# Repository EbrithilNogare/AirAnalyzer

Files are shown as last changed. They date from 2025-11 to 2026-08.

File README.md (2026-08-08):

# 🌡️ AirAnalyzer

A DIY ESP32-based environmental monitor with an e-paper display!

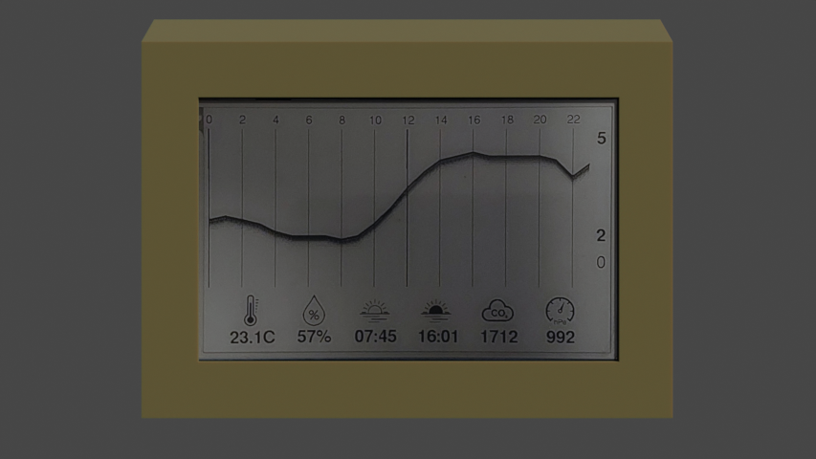
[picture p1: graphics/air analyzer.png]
Device
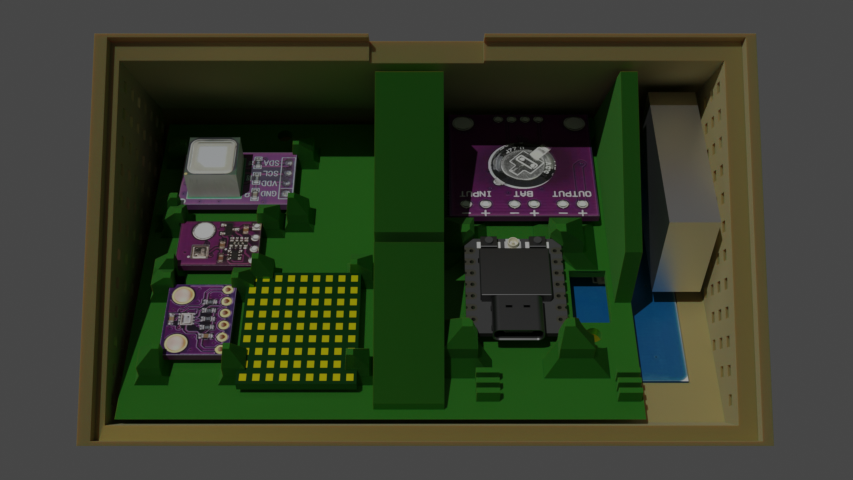
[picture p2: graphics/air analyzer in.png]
Internals
|||
|:--:|:--:|
|Outside|Inside|

## What it does

- Measures **temperature**, **humidity**, **CO2**, and **pressure**
- Fetches **weather forecast** from Open-Meteo API
- Shows **sunrise/sunset** times
- Uploads data to **ThingSpeak**
- Runs on **deep sleep** for low power consumption

## Hardware

- ESP32-C3
- SCD40 (CO2 sensor)
- SHT4x (temperature & humidity)
- BMP280 (pressure)
- 3.97" e-paper display

## Connections

```mermaid
---
config:
  layout: elk
---
flowchart LR
    ESP["ESP32-C3<br>Seeed Studio"] -- "3V3 - VCC<br>GND - GND<br>GPIO 6 - SDA<br>GPIO 7 - SCL<br>BAT+ - BAT+<br>BAT- - BAT-" --- Board["Board"]

    Board -- "VCC - VCC<br>GND - GND<br>SCL - SCL<br>SDA - SDA" --- SCD40["SCD40"] & SHT4x["SHT4x"] & BMP280["BMP280"]

    ESP -- "GPIO 20 - Base" --- Transistor["BC327 PNP Transistor"]
    Transistor -- "Collector - VCC" --- Display["E-Paper Display"]
    ESP -- "GPIO 9 - PWR" --- Display
    ESP -- "GPIO 3 - BUSY" --- Display
    ESP -- "GPIO 4 - RST" --- Display
    ESP -- "GPIO 5 - DC" --- Display
    ESP -- "GPIO 21 - CS" --- Display
    ESP -- "GPIO 8 - SCLK" --- Display
    ESP -- "GPIO 10 - DIN" --- Display
    ESP -- "GND - GND" --- Display
    ESP -- "3V3 - Emitter" --- Transistor

    ESP -- "BAT+ - BAT+" --- Charger["CJMCU-2557"]
    ESP -- "BAT- - BAT-" --- Charger
    Battery["LiPo Battery<br>500 mAh"] -- "Positive - BAT+" --- Charger
    Battery -- "Negative - BAT-" --- Charger
    Solar["Solar Panel"] -- "Positive - Input +" --- Charger
    Solar -- "Negative - Input -" --- Charger
    Solar -- "Zener diode (1N4733 5V1)" --- Solar

    ESP:::controller
    Board:::board
    SCD40:::sensor
    SHT4x:::sensor
    BMP280:::sensor
    Transistor:::transistor
    Display:::display
    Charger:::charger
    Battery:::battery
    Solar:::solar

    classDef controller stroke:#818cf8,fill:#eef2ff
    classDef board stroke:#fb923c,fill:#fff7ed
    classDef sensor stroke:#4ade80,fill:#f0fdf4
    classDef transistor stroke:#f87171,fill:#fef2f2
    classDef display stroke:#a78bfa,fill:#f5f3ff
    classDef charger stroke:#22d3ee,fill:#ecfeff
    classDef battery stroke:#facc15,fill:#fefce8
    classDef solar stroke:#fb923c,fill:#fff7ed
```

## Setup

1. Copy `include/config.example.h` to `include/config.h`
2. Add your WiFi credentials and ThingSpeak API key
3. Build & upload with PlatformIO

---

_Icons converted using [image2cpp](https://javl.github.io/image2cpp/)_

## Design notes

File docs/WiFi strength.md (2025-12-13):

# Consumtion estimation

| Power | Consumtion |
| ---: | ---: |
| -1 dBm | 165 mA |
| 2 dBm | 170 mA |
| 5 dBm | 178 mA |
| 7 dBm | 185 mA |
|  8.5 dBm | 192 mA |
| 11 dBm | 205 mA |
| 13 dBm | 220 mA |
| 15 dBm | 240 mA |
| 17 dBm | 260 mA |
| 18.5 dBm | 277 mA |
| 19 dBm | 285 mA |
| 19.5 dBm | 300 mA |

# Wifi connection measurement

## WIFI_PS_NONE

| Power Level | Success | Failed | Success% | Min(ms) | Avg(ms) | Max(ms) |
| ---: | ---: | -----: | ---: | ---: | ---: | ---: |
| -1dBm | 10 | 0 | 100.0% | 917 | 1321 | 1516 |
| 2dBm | 10 | 0 | 100.0% | 917 | 1330 | 1624 |
| 5dBm | 10 | 0 | 100.0% | 914 | 1260 | 1664 |
| 7dBm | 10 | 0 | 100.0% | 960 | 1298 | 1679 |
| 8.5dBm | 10 | 0 | 100.0% | 914 | 1160 | 1490 |
| 11dBm | 10 | 0 | 100.0% | 915 | 1334 | 1501 |
| 13dBm | 10 | 0 | 100.0% | 979 | 1380 | 1558 |
| 15dBm | 10 | 0 | 100.0% | 926 | 1299 | 1594 |
| 17dBm | 10 | 0 | 100.0% | 914 | 1294 | 1613 |
| 18.5dBm | 10 | 0 | 100.0% | 966 | 1324 | 1518 |
| 19dBm | 10 | 0 | 100.0% | 912 | 1100 | 1486 |
| 19.5dBm | 10 | 0 | 100.0% | 920 | 1151 | 1545 |

## WIFI_PS_MAX_MODEM

| Power Level | Success | Failed | Success% | Min(ms) | Avg(ms) | Max(ms) |
| ---: | ---: | -----: | ---: | ---: | ---: | ---: |
| -1dBm | 10 | 0 | 100.0% | 939 | 1485 | 2173 |
| 2dBm | 10 | 0 | 100.0% | 972 | 1304 | 1695 |
| 5dBm | 10 | 0 | 100.0% | 1003 | 1276 | 1608 |
| 7dBm | 10 | 0 | 100.0% | 915 | 1421 | 1647 |
| 8.5dBm | 10 | 0 | 100.0% | 915 | 1365 | 1836 |
| 11dBm | 10 | 0 | 100.0% | 976 | 1313 | 1782 |
| 13dBm | 10 | 0 | 100.0% | 959 | 1335 | 1575 |
| 15dBm | 10 | 0 | 100.0% | 916 | 1411 | 1578 |
| 17dBm | 10 | 0 | 100.0% | 911 | 1476 | 1931 |
| 18.5dBm | 10 | 0 | 100.0% | 914 | 1400 | 1615 |
| 19dBm | 10 | 0 | 100.0% | 998 | 1356 | 1591 |
| 19.5dBm | 10 | 0 | 100.0% | 984 | 1411 | 1671 |

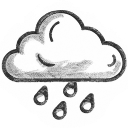
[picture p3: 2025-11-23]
graphics/rain.png

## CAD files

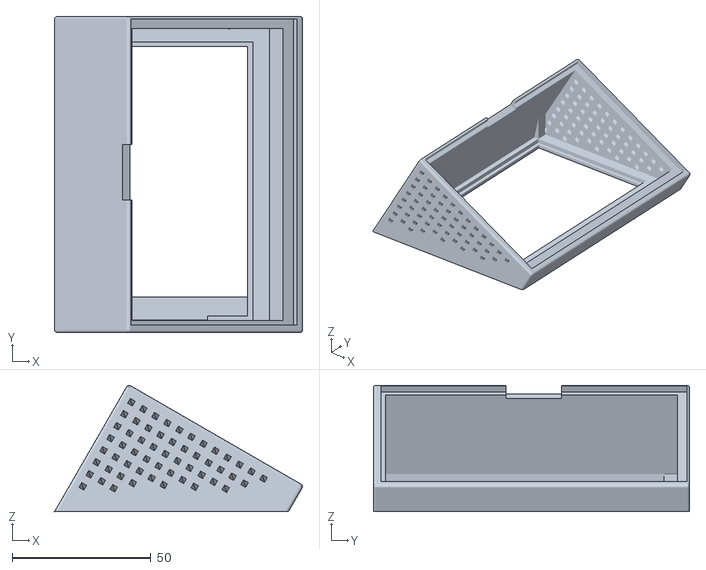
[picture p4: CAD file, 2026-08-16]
models/bottom part.stl
89.4 x 114.0 x 45.5

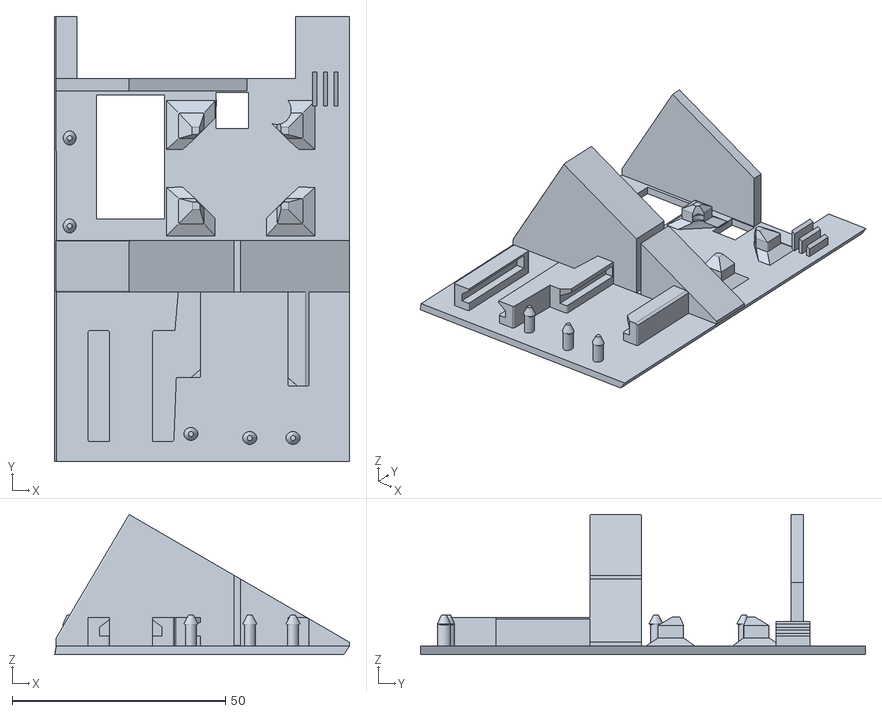
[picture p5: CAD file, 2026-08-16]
models/middle part.stl
69.1 x 104.3 x 32.8

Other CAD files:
models/air analyzer.blend

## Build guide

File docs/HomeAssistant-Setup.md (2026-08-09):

# Home Assistant Setup Guide

This guide explains how to set up Home Assistant to receive sensor data from your AirAnalyzer device.

## Overview

The AirAnalyzer sends the following sensor data to Home Assistant:

- **temperature**: Air temperature from SHT4x sensor (°C)
- **temperature_esp**: ESP32 internal temperature (°C)
- **humidity**: Relative humidity from SHT4x sensor (%)
- **co2**: CO₂ concentration from SCD40 sensor (ppm)
- **pressure**: Atmospheric pressure from BMP280 sensor (hPa)
- **battery_voltage**: Battery voltage (V)
- **temperature_scd**: Air temperature from SCD40 sensor (°C)
- **humidity_scd**: Relative humidity from SCD40 sensor (%)
- **wifi_rssi**: WiFi signal strength (dBm)

## Setup Steps

### 1. Create Webhook Automation in Home Assistant

1. Go to **Settings** → **Automations & Scenes**
2. Click **+ Create Automation** → **Create new automation**
3. Click the **⋮** menu → **Edit in YAML**
4. Replace with this configuration:

```yaml
alias: AirAnalyzer Data Receiver
description: Receives sensor data from AirAnalyzer device
trigger:
  - platform: webhook
    webhook_id: air_analyzer # use real id, as it is as password
    allowed_methods:
      - POST
    local_only: true
condition: []
action:
  - event: air_analyzer_data_received
    event_data:
      temperature: "{{ trigger.json.temperature }}"
      temperature_esp: "{{ trigger.json.temperature_esp }}"
      humidity: "{{ trigger.json.humidity }}"
      co2: "{{ trigger.json.co2 }}"
      pressure: "{{ trigger.json.pressure }}"
      battery_voltage: "{{ trigger.json.battery_voltage }}"
      temperature_scd: "{{ trigger.json.temperature_scd }}"
      humidity_scd: "{{ trigger.json.humidity_scd }}"
      wifi_rssi: "{{ trigger.json.wifi_rssi }}"
mode: single
```

5. Click **Save**

### 2. Add Sensors to Configuration

Add the following to your `configuration.yaml`:

```yaml
# AirAnalyzer Sensors
template:
  - trigger:
      - platform: event
        event_type: air_analyzer_data_received
    sensor:
      - name: "Air Analyzer Temperature"
        unique_id: air_analyzer_temperature
        state: "{{ trigger.event.data.temperature }}"
        unit_of_measurement: "°C"
        device_class: temperature
        state_class: measurement
      - name: "Air Analyzer Humidity"
        unique_id: air_analyzer_humidity
        state: "{{ trigger.event.data.humidity }}"
        unit_of_measurement: "%"
        device_class: humidity
        state_class: measurement
      - name: "Air Analyzer CO₂"
        unique_id: air_analyzer_co2
        state: "{{ trigger.event.data.co2 }}"
        unit_of_measurement: "ppm"
        device_class: carbon_dioxide
        state_class: measurement
      - name: "Air Analyzer Pressure"
        unique_id: air_analyzer_pressure
        state: "{{ trigger.event.data.pressure }}"
        unit_of_measurement: "hPa"
        device_class: atmospheric_pressure
        state_class: measurement
      - name: "Air Analyzer Battery"
        unique_id: air_analyzer_battery
        state: "{{ trigger.event.data.battery_voltage }}"
        unit_of_measurement: "V"
        device_class: voltage
        state_class: measurement
      - name: "Air Analyzer ESP Temperature"
        unique_id: air_analyzer_esp_temperature
        state: "{{ trigger.event.data.temperature_esp }}"
        unit_of_measurement: "°C"
        device_class: temperature
        state_class: measurement
      - name: "Air Analyzer SCD Temperature"
        unique_id: air_analyzer_scd_temperature
        state: "{{ trigger.event.data.temperature_scd }}"
        unit_of_measurement: "°C"
        device_class: temperature
        state_class: measurement
      - name: "Air Analyzer SCD Humidity"
        unique_id: air_analyzer_scd_humidity
        state: "{{ trigger.event.data.humidity_scd }}"
        unit_of_measurement: "%"
        device_class: humidity
        state_class: measurement
      - name: "Air Analyzer WiFi RSSI"
        unique_id: air_analyzer_wifi_rssi
        state: "{{ trigger.event.data.wifi_rssi }}"
        unit_of_measurement: "dBm"
        device_class: signal_strength
        state_class: measurement
      - name: "Air Analyzer Last Seen"
        unique_id: air_analyzer_last_seen
        device_class: timestamp
        state: "{{ now() }}"
```

After adding this, restart Home Assistant.

### 3. Add Sensors to Dashboard

The sensors will appear as:

- `sensor.air_analyzer_temperature`
- `sensor.air_analyzer_humidity`
- `sensor.air_analyzer_co2`
- `sensor.air_analyzer_pressure`
- `sensor.air_analyzer_battery`
- `sensor.air_analyzer_esp_temperature`
- `sensor.air_analyzer_scd_temperature`
- `sensor.air_analyzer_scd_humidity`
- `sensor.air_analyzer_wifi_rssi`

1. Go to your dashboard
2. Click **Edit Dashboard** → **+ Add Card** → **Entities Card**
3. Add these entities to display your sensor data

## Testing

### Test the Webhook

You can test the webhook from your computer using curl:

```bash
curl -X POST http://homeassistant.local:8123/api/webhook/XXXXX -H "Content-Type: application/json" -d '{ "temperature": 22.5, "temperature_esp": 35.2, "humidity": 45.3, "co2": 650, "pressure": 1013, "battery_voltage": 4.15, "temperature_scd": 22.8, "humidity_scd": 44.7, "wifi_rssi": -62 }'
```

If successful, you should see the values update in your Home Assistant helpers.

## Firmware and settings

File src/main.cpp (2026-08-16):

#include "PinConfig.h"
#include <Arduino.h>
#include <Wire.h>
#include <WiFi.h>
#include <HTTPClient.h>
#include <Adafruit_SHT4x.h>
#include <Adafruit_BMP280.h>
#include <SensirionI2CScd4x.h>
#include <GxEPD2_BW.h>
#include <ArduinoJson.h>
#include <esp_sleep.h>
#include <time.h>

#include "../include/config.h"
#include "rendering.h"
#include "home_assistant.h"



DisplayType display(GxEPD2_397_GDEM0397T81(EPD_CS_PIN, EPD_DC_PIN, EPD_RST_PIN, EPD_BUSY_PIN));
Adafruit_SHT4x sht4;
Adafruit_BMP280 bmp;
SensirionI2cScd4x scd4x;

float tempAir = NAN, humidity = NAN, tempESP = NAN, pressure = NAN, batteryVoltage = NAN, co2 = NAN, moonPhase = 0;
float tempSCD = NAN, humiditySCD = NAN;
int wifiRSSI = 0;


RTC_DATA_ATTR float rtc_forecastTemp[FORECAST_FETCH_HOURS];
RTC_DATA_ATTR float rtc_forecastApparentTemp[FORECAST_FETCH_HOURS];
RTC_DATA_ATTR float rtc_forecastRain[FORECAST_FETCH_HOURS];
RTC_DATA_ATTR char rtc_sunriseTimeStr[6] = "--:--";
RTC_DATA_ATTR char rtc_sunsetTimeStr[6] = "--:--";
RTC_DATA_ATTR int rtc_forecastStartHour = 0;
RTC_DATA_ATTR int rtc_forecastValidHours = 0;      // how many hours the last fetch actually returned
RTC_DATA_ATTR uint32_t rtc_forecastStartEpoch = 0; // epoch of forecast index 0, used to re-align the graph on the current hour
RTC_DATA_ATTR uint32_t rtc_lastWeatherSlot = 0;     // fetch slot whose data is already in RTC memory
RTC_DATA_ATTR bool rtc_weatherDataValid = false;
RTC_DATA_ATTR uint32_t rtc_bootCount = 0;
RTC_DATA_ATTR uint32_t rtc_ntpBaseEpoch = 0;            // Unix epoch at last NTP sync
RTC_DATA_ATTR uint64_t rtc_elapsedUs = 0;               // Microseconds elapsed since NTP sync
RTC_DATA_ATTR uint64_t rtc_priorAwakeUs = 0;            // Previous cycle awake time (XTAL-timed, accurate)
RTC_DATA_ATTR uint64_t rtc_priorSleepUs = 0;            // Previous cycle intended sleep duration

// Measured true-seconds-per-requested-second of the deep sleep timer (see calibrateSleepClock)
RTC_DATA_ATTR float rtc_clockScale = 1.0f;
RTC_DATA_ATTR uint64_t rtc_sleepUsSinceSync = 0;
RTC_DATA_ATTR uint64_t rtc_awakeUsSinceSync = 0;

RTC_DATA_ATTR int rtc_batteryPercent = 0;  // battery percentage shown on display
RTC_DATA_ATTR uint32_t rtc_lastFullUpdateEpoch = 0;  // Epoch of last display refresh
RTC_DATA_ATTR uint32_t rtc_lastGraphHash = 0;        // fingerprint of the graph as it is currently on the panel

// Last known-good association, replayed on the next wake to skip the channel scan and DHCP
RTC_DATA_ATTR uint8_t rtc_wifiBssid[6] = {0};
RTC_DATA_ATTR uint8_t rtc_wifiChannel = 0;
RTC_DATA_ATTR uint32_t rtc_wifiIp = 0;
RTC_DATA_ATTR uint32_t rtc_wifiGateway = 0;
RTC_DATA_ATTR uint32_t rtc_wifiSubnet = 0;
RTC_DATA_ATTR uint32_t rtc_wifiDns = 0;
RTC_DATA_ATTR bool rtc_wifiCacheValid = false;
RTC_DATA_ATTR uint8_t rtc_netFailStreak = 0;  // consecutive cycles where a POST never reached the server

// NTP reports whole seconds, so a window this short measures the oscillator to only ~0.1%. That is
// enough to remove most of a 2% error on the second boot; the daily syncs afterwards refine it.
const uint64_t CALIBRATION_MIN_SLEEP_US = 900ULL * 1000000ULL;
const uint32_t CALIBRATION_BOOTS = 2;

// ################################ Moon Phase #################################

// Returns moon phase as percentage: 0.0 = new moon, 0.5 = full moon, 1.0 = new moon
void getMoonPhase(uint32_t epochTime) {
  const uint32_t FULL_MOON_REF = 1763614318;
  const uint32_t LUNAR_CYCLE = 2551443; // 29.53 days in seconds
  uint32_t elapsed = epochTime - FULL_MOON_REF;
  moonPhase = (float)(elapsed % LUNAR_CYCLE) / (float)LUNAR_CYCLE;
}

// ################################ Sensors ####################################

bool shtOk = false, bmpOk = false;

// Every sensor needs some time between the command that starts it and the read that collects the result.
// Each one records the millis() deadline it becomes readable at, and the reader waits out whatever is left
// of it - work done on another sensor in between counts towards the wait instead of being added to it.
uint32_t shtReadyAtMs = 0, bmpReadyAtMs = 0, scdReadyAtMs = 0;

const uint32_t SHT4X_RESET_MS = 2;      // soft reset, datasheet says ready within 1 ms
const uint32_t BMP280_CONVERSION_MS = 13;  // 1.25 + 2*osrs_t + (2*osrs_p + 0.5) = 11.75 ms at X1 temp / X4 pressure
const uint32_t SCD40_STOP_MS = 500;     // sensor ignores commands until this elapses after a stop
const uint32_t SCD40_REINIT_MS = 30;
const uint32_t SCD40_FIRST_SAMPLE_MS = 5000;  // signal update interval

// Sleep the CPU while a sensor works; radios are still off at this point in the cycle so light sleep is safe
void lightSleepMs(uint32_t ms) {
  esp_sleep_enable_timer_wakeup((uint64_t)ms * 1000ULL);
  esp_light_sleep_start();
}

// millis() keeps counting across light sleep, so the deadlines stay comparable either way. Short waits use
// delay(), the light sleep entry/exit costs more than a couple of milliseconds of running.
void waitUntilMs(uint32_t readyAtMs) {
  int32_t remainingMs = (int32_t)(readyAtMs - millis());  // signed difference, so a passed deadline is negative
  if (remainingMs <= 0) return;
  if (remainingMs < 20) delay(remainingMs);
  else lightSleepMs((uint32_t)remainingMs);
}

void initSensors() {
  Wire.begin(I2C_SDA_PIN, I2C_SCL_PIN, 100000);
  delay(2);

  shtOk = sht4.begin(&Wire);
  if (shtOk) {
    sht4.setPrecision(SHT4X_HIGH_PRECISION);
    sht4.setHeater(SHT4X_NO_HEATER);
    shtReadyAtMs = millis() + SHT4X_RESET_MS;  // begin() issues a soft reset
  }

  bmpOk = bmp.begin(BMP280_ADDRESS_ALT);
  bmpReadyAtMs = millis();  // begin() already waits out its own settling time

  scd4x.begin(Wire, SCD40_I2C_ADDR_62);
  scdReadyAtMs = millis();

  analogReadResolution(12);
  analogSetAttenuation(ADC_11db);
  pinMode(POWER_SENSING_PIN, INPUT);
}

// The SCD40 keeps its periodic mode across ESP resets and start-while-measuring is a forbidden command, so always stop first (sensor responds again 500 ms after stop)
bool startSCD() {
  waitUntilMs(scdReadyAtMs);
  scd4x.stopPeriodicMeasurement();
  scdReadyAtMs = millis() + SCD40_STOP_MS;
  waitUntilMs(scdReadyAtMs);

  if (scd4x.startPeriodicMeasurement() == 0) {
    scdReadyAtMs = millis() + SCD40_FIRST_SAMPLE_MS;
    return true;
  }

  scd4x.reinit();  // self-heal: reload sensor settings and retry once
  scdReadyAtMs = millis() + SCD40_REINIT_MS;
  waitUntilMs(scdReadyAtMs);
  if (scd4x.startPeriodicMeasurement() != 0) return false;

  scdReadyAtMs = millis() + SCD40_FIRST_SAMPLE_MS;
  return true;
}

// First sample arrives after the ~5 s signal update interval; sleep most of it, then poll data-ready (a read before that would just NACK)
void finishSCD(bool scdStarted) {
  if (!scdStarted) return;

  waitUntilMs(scdReadyAtMs);  // whatever the BMP280 and SHT4x took already counts towards the 5 s
  bool dataReady = false;
  for (int i = 0; i < 10 && !(scd4x.getDataReadyStatus(dataReady) == 0 && dataReady); i++) {
    lightSleepMs(250);
  }

  if (dataReady) {
    uint16_t co2Raw;
    float t, h;
    if (scd4x.readMeasurement(co2Raw, t, h) == 0 && co2Raw != 0) {
      co2 = co2Raw;
      tempSCD = t;
      humiditySCD = h;
    }
  }

  scd4x.stopPeriodicMeasurement();
  scdReadyAtMs = millis() + SCD40_STOP_MS;  // not waited out here, the next command is a full cycle away

  if (co2 > 10000) co2 = NAN;
}

void readSensorBMP() {
  if (!bmpOk) {
    bmpOk = bmp.begin(BMP280_ADDRESS_ALT);  // self-heal from a failed init
    bmpReadyAtMs = millis();
  }
  if (!bmpOk) return;

  waitUntilMs(bmpReadyAtMs);
  bmp.setSampling(Adafruit_BMP280::MODE_FORCED,
                  Adafruit_BMP280::SAMPLING_X1,  // temperature
                  Adafruit_BMP280::SAMPLING_X4,  // pressure (reduced from X16 for power savings)
                  Adafruit_BMP280::FILTER_OFF);
  bmp.takeForcedMeasurement();  // Wake, measure, return to sleep
  // takeForcedMeasurement polls the status bit immediately after triggering and the chip does not raise it
  // instantly, so the poll can fall through and the read return the previous conversion
  bmpReadyAtMs = millis() + BMP280_CONVERSION_MS;
  waitUntilMs(bmpReadyAtMs);
  float hPa = bmp.readPressure() / 100.0f;

  if (isnan(hPa) || hPa < 300 || hPa > 1200) return;  // pressure stays NaN

  pressure = hPa;
  scd4x.setAmbientPressure((uint32_t)(hPa * 100));  // allowed while the SCD40 measures
}

void readSensorSHT() {
  if (!shtOk) return;

  waitUntilMs(shtReadyAtMs);
  sensors_event_t hum, temp;
  bool ok = sht4.getEvent(&hum, &temp);  // getEvent blocks for the conversion itself
  if (!ok) {  // self-heal: soft reset (sensor ready again within 1 ms) and retry once
    sht4.reset();
    shtReadyAtMs = millis() + SHT4X_RESET_MS;
    waitUntilMs(shtReadyAtMs);
    ok = sht4.getEvent(&hum, &temp);
  }
  if (!ok) return;  // getEvent leaves the structs untouched on failure, never read them then

  tempAir = temp.temperature;
  humidity = hum.relative_humidity;
  if (humidity < 0 || humidity > 100) humidity = NAN;
  if (tempAir < -40 || tempAir > 100) tempAir = NAN;
}

void readSensorBatteryVoltage(){
  uint32_t batteryVoltageSum = 0;
  for (int i = 0; i < BATTERY_AVERAGE_SAMPLES; i++) {
    batteryVoltageSum += analogReadMilliVolts(POWER_SENSING_PIN);
  }
  batteryVoltage = (batteryVoltageSum / static_cast<float>(BATTERY_AVERAGE_SAMPLES)) * VOLTAGE_DIVIDER_RATIO / 1000.0;
}

void readSensors() {
  readSensorBatteryVoltage();
  tempESP = temperatureRead();
  bool scdStarted = startSCD();
  readSensorBMP();  // runs during the SCD40 warm-up and feeds it the ambient pressure
  readSensorSHT();
  finishSCD(scdStarted);
}

// ############################### Internet ####################################

const int WIFI_FAST_TIMEOUT_MS = 4000;   // a replayed association normally completes in ~300 ms
const int WIFI_FULL_TIMEOUT_MS = 10000;

bool waitForWiFi(int timeoutMs) {
  for (int i = 0; i < timeoutMs && WiFi.status() != WL_CONNECTED; i+=50){
    delay(50);
  }
  return WiFi.status() == WL_CONNECTED;
}

void applyRadioSettings() {
  WiFi.mode(WIFI_STA);
  WiFi.setTxPower(WIFI_POWER_5dBm);
  WiFi.setSleep(WIFI_PS_NONE);
}

void cacheWiFiParams() {
  const uint8_t* bssid = WiFi.BSSID();
  uint32_t ip = (uint32_t)WiFi.localIP();
  if (bssid == nullptr || ip == 0 || WiFi.channel() == 0) return;

  memcpy(rtc_wifiBssid, bssid, sizeof(rtc_wifiBssid));
  rtc_wifiChannel = (uint8_t)WiFi.channel();
  rtc_wifiIp = ip;
  rtc_wifiGateway = (uint32_t)WiFi.gatewayIP();
  rtc_wifiSubnet = (uint32_t)WiFi.subnetMask();
  rtc_wifiDns = (uint32_t)WiFi.dnsIP();
  rtc_wifiCacheValid = true;
}

// Replaying the last working BSSID, channel and lease skips the channel scan and DHCP, turning a ~1.3 s
// association into ~300 ms. Anything that goes wrong falls back to a full scan in the same wake.
bool connectWiFi() {
  WiFi.persistent(false);  // the cache lives in RTC memory, no need for a flash write every boot
  applyRadioSettings();

  if (rtc_wifiCacheValid) {
    WiFi.config(IPAddress(rtc_wifiIp), IPAddress(rtc_wifiGateway), IPAddress(rtc_wifiSubnet), IPAddress(rtc_wifiDns));
    WiFi.begin(WIFI_SSID, WIFI_PASSWORD, rtc_wifiChannel, rtc_wifiBssid);
    if (waitForWiFi(WIFI_FAST_TIMEOUT_MS)) return true;

    rtc_wifiCacheValid = false;
    WiFi.disconnect(true);
    delay(10);
    applyRadioSettings();
  }

  const IPAddress unset((uint32_t)0);
  WiFi.config(unset, unset, unset, unset);  // a zeroed config is what the core reads as "use DHCP"
  WiFi.begin(WIFI_SSID, WIFI_PASSWORD);
  if (!waitForWiFi(WIFI_FULL_TIMEOUT_MS)) return false;

  cacheWiFiParams();
  return true;
}

void disconnectWiFi() {
  WiFi.disconnect(true, false);
  WiFi.mode(WIFI_OFF);
}

// The Unix epoch is UTC-aligned, so counting whole intervals from the anchor lands the slots on the
// configured wall-clock times.
uint32_t currentWeatherSlot(uint32_t epoch) {
  if (epoch < WEATHER_FETCH_ANCHOR_UTC_SECONDS) return 0;
  uint32_t sinceAnchor = epoch - WEATHER_FETCH_ANCHOR_UTC_SECONDS;
  return (sinceAnchor / WEATHER_FETCH_INTERVAL_SECONDS) * WEATHER_FETCH_INTERVAL_SECONDS
         + WEATHER_FETCH_ANCHOR_UTC_SECONDS;
}

void fetchWeatherForecast(uint32_t currentEpoch) {
  if (WiFi.status() != WL_CONNECTED) return;

  String url = String("https://api.open-meteo.com/v1/forecast?latitude=50.06&longitude=14.419998"
                      "&timezone=Europe%2FBerlin&forecast_days=2"
                      "&hourly=temperature_2m,apparent_temperature,rain,snowfall"
                      "&daily=sunset,sunrise&models=icon_d2&forecast_hours=") + FORECAST_FETCH_HOURS;

  HTTPClient http;
  http.begin(url);

  int httpCode = http.GET();
  if (httpCode == 200) {
    String payload = http.getString();
    
    JsonDocument doc;
    DeserializationError error = deserializeJson(doc, payload);
    
    if (error) {
      http.end();
      return;
    }
    
    // Parse hourly temperature and rain
    JsonArray tempArray = doc["hourly"]["temperature_2m"];
    JsonArray apparentTempArray = doc["hourly"]["apparent_temperature"];
    JsonArray rainArray = doc["hourly"]["rain"];
    JsonArray snowArray = doc["hourly"]["snowfall"];
    JsonArray timeArray = doc["hourly"]["time"];
    
    if (timeArray.size() > 0) {
      String firstTime = timeArray[0].as<String>();
      rtc_forecastStartHour = firstTime.substring(11, 13).toInt();
    }

    int hours = 0;
    for (int i = 0; i < FORECAST_FETCH_HOURS && i < (int)tempArray.size(); i++) {
      rtc_forecastTemp[i] = tempArray[i];
      rtc_forecastApparentTemp[i] = apparentTempArray[i] | rtc_forecastTemp[i];
      // Combine rain and snowfall (snowfall in cm, convert to mm equivalent)
      float rain = rainArray[i] | 0.0f;
      float snow = snowArray[i] | 0.0f;
      rtc_forecastRain[i] = rain + (snow * 10.0f);  // 1cm snow ≈ 10mm water
      hours++;
    }
    if (hours == 0) {
      http.end();
      return;
    }
    rtc_forecastValidHours = hours;
    // The API returns the hourly series starting at the current hour
    rtc_forecastStartEpoch = currentEpoch - (currentEpoch % 3600UL);
    rtc_lastWeatherSlot = currentWeatherSlot(currentEpoch);

    // Parse sunrise and sunset times
    if (doc["daily"]["sunrise"][0]) {
      String sunriseStr = doc["daily"]["sunrise"][0].as<String>();
      String sunriseShort = sunriseStr.substring(11, 16); // Extract HH:MM
      sunriseShort.toCharArray(rtc_sunriseTimeStr, 6);
    }
    if (doc["daily"]["sunset"][0]) {
      String sunsetStr = doc["daily"]["sunset"][0].as<String>();
      String sunsetShort = sunsetStr.substring(11, 16); // Extract HH:MM
      sunsetShort.toCharArray(rtc_sunsetTimeStr, 6);
    }
    rtc_weatherDataValid = true;
  }

  http.end();
}

// ################################ Display ####################################

// Fingerprint of everything the graph draws, so a redraw can tell whether the shape on the panel is still
// the right one. Values are quantised to a tenth, well below what a pixel can show, so float noise in an
// otherwise identical forecast does not read as a change.
uint32_t graphContentHash(const float* temp, const float* apparentTemp, const float* rain, int hours, int startHour, bool valid) {
  uint32_t hash = 2166136261u;  // FNV-1a
  auto mix = [&hash](uint32_t v) { hash = (hash ^ v) * 16777619u; };

  mix(valid ? 1u : 0u);
  mix((uint32_t)hours);
  mix((uint32_t)startHour);
  for (int i = 0; i < hours; i++) {
    mix((uint32_t)lroundf(temp[i] * 10.0f));
    mix((uint32_t)lroundf(apparentTemp[i] * 10.0f));
    mix((uint32_t)lroundf(rain[i] * 10.0f));
  }
  return hash;
}

void initDisplay1() {
  // BC327 is PNP transistor - LOW turns it ON (provides power to display)
  pinMode(EPD_TRANSISTOR_PIN, OUTPUT);
  digitalWrite(EPD_TRANSISTOR_PIN, LOW);  // Turn on transistor to power display
  
  pinMode(EPD_PWR_PIN, OUTPUT);
  digitalWrite(EPD_PWR_PIN, HIGH);
}

void initDisplay2() {
  display.init(115200, false, 2, false);
  display.setRotation(2); // landscape
  display.setTextColor(GxEPD_BLACK);
}

void turnOffDisplay() {
  display.powerOff();
  digitalWrite(EPD_PWR_PIN, LOW);
  pinMode(EPD_CS_PIN, INPUT);
  pinMode(EPD_DC_PIN, INPUT);
  pinMode(EPD_SCK_PIN, INPUT);
  pinMode(EPD_MOSI_PIN, INPUT);
  pinMode(EPD_RST_PIN, INPUT);
  pinMode(EPD_BUSY_PIN, INPUT);
  digitalWrite(EPD_TRANSISTOR_PIN, LOW);
}

// ################################ Time #####################################

uint32_t getCurrentEpoch() {
  return rtc_ntpBaseEpoch + (uint32_t)(rtc_elapsedUs / 1000000ULL);
}

// The deep sleep timer counts on the internal RC oscillator, good to a couple of percent, and the cycle
// bookkeeping assumes a sleep lasted exactly as long as it was asked to. That error only accumulates in
// one direction, so NTP measures how far the last stretch of sleep really ran and the ratio divides
// subsequent sleep requests. Awake time is excluded, millis() runs off the accurate 40 MHz crystal.
void calibrateSleepClock(uint32_t oldNtpBase, uint32_t newEpoch) {
  if (oldNtpBase == 0) return;
  if (rtc_sleepUsSinceSync < CALIBRATION_MIN_SLEEP_US) return;

  int64_t trueElapsedUs = ((int64_t)newEpoch - (int64_t)oldNtpBase) * 1000000LL;
  int64_t trueSleepUs = trueElapsedUs - (int64_t)rtc_awakeUsSinceSync;
  if (trueSleepUs <= 0) return;

  // Composes, because rtc_clockScale was already applied when those sleeps were requested
  float scale = rtc_clockScale * ((float)trueSleepUs / (float)rtc_sleepUsSinceSync);
  if (scale < 0.95f || scale > 1.05f) return;  // bad NTP answer or lost RTC state, not a real oscillator

  rtc_clockScale = scale;
}

bool syncNTP() {
  uint32_t oldEpoch = getCurrentEpoch();

  configTzTime(TIMEZONE, "pool.ntp.org");
  struct tm timeinfo;
  if (!getLocalTime(&timeinfo, 5000)) return false;

  uint32_t newEpoch = (uint32_t)mktime(&timeinfo);
  int32_t timeDrift = rtc_ntpBaseEpoch == 0 ? 0 : (int32_t)(newEpoch - oldEpoch);

  calibrateSleepClock(rtc_ntpBaseEpoch, newEpoch);
  rtc_sleepUsSinceSync = 0;
  rtc_awakeUsSinceSync = 0;

  rtc_ntpBaseEpoch = newEpoch;
  rtc_elapsedUs = 0;

  rtc_lastFullUpdateEpoch += timeDrift;

  return true;
}

// ####################### Home Assistant task ###############################

volatile bool haSendDone = false;
volatile int haSendResult = 0;

void haSendTask(void* param) {
  haSendResult = sendToHomeAssistant(tempAir, tempESP, humidity, co2, pressure, batteryVoltage, tempSCD, humiditySCD, wifiRSSI);
  haSendDone = true;
  vTaskDelete(NULL);
}

// Associating is not the same as being reachable: a cached lease the router has since handed to another
// device still reports WL_CONNECTED while every request times out, and nothing else would clear it.
void noteNetworkResult(int httpCode) {
  if (httpCode > 0) {
    rtc_netFailStreak = 0;
    return;
  }
  if (rtc_netFailStreak < 255) rtc_netFailStreak++;
  if (rtc_netFailStreak >= 3) {
    rtc_wifiCacheValid = false;
    rtc_netFailStreak = 0;
  }
}

// ################################ Setup ####################################
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
void loop() {
  // Not used, all logic in setup for deep sleep cycle
}

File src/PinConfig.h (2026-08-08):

#ifndef PIN_CONFIG_H
#define PIN_CONFIG_H

/**
 * GPIO config
**/
#define POWER_SENSING_PIN  2  // Power sniffing

#define EPD_TRANSISTOR_PIN 20  // BC327 transistor control for display power
#define EPD_PWR_PIN    9  // Power control
#define EPD_BUSY_PIN   3  // Busy signal from display
#define EPD_RST_PIN    4  // Reset
#define EPD_DC_PIN     5  // Data/Command
#define EPD_CS_PIN    21  // Chip Select
#define EPD_SCK_PIN    8  // SPI Clock (standard ESP32C3 SPI)
#define EPD_MOSI_PIN  10  // SPI MOSI (standard ESP32C3 SPI)

// I2C pins for sensors (SHT4x, SDC40)
#define I2C_SDA_PIN    6  // I2C SDA
#define I2C_SCL_PIN    7  // I2C SCL

#define BATTERY_AVERAGE_SAMPLES 64  // Number of samples to average for battery voltage reading
#define VOLTAGE_DIVIDER_RATIO 1.983f // Voltage divider ratio for battery voltage measurement

#endif

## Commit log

2025-12-02 added pressure sensor
2025-12-04 model on landscape
    [bottom part.stl, middle part.stl]
2025-12-04 refactor: replace GxEPD2_BW type with DisplayType for consistency and clarity
    [main.cpp]
2025-12-05 feat: initialize CO2 sensor on first boot and improve rendering logic
2025-12-05 finished model
    [bottom part.stl, middle part.stl]
2025-12-06 iimproved sleep power efficiency
2025-12-07 Refine sensor data handling and display formatting for improved accuracy
2025-12-07 added battery voltage sensiing
2025-12-10 Implement sleep mode for SCD sensor and adjust delays in setup
2025-12-13 exported models
    [bottom part.stl, middle part.stl]
2025-12-13 fixed presure and make co2 working again
    [main.cpp]
2025-12-13 improved wifi power consumtion
2025-12-14 add display power control and anti-ghosting functions
2025-12-20 fixed co2 sensor
2026-01-15 Refactor configuration files: replace include guards with #pragma once, remove legacy ThingSpeak integration
    [main.cpp]
2026-01-16 fixed wrong documentation record
    [main.cpp]
2026-01-26 fixed pressure set for co2
    [main.cpp]
2026-03-21 added apparent temperature
2026-03-21 better power efficiency
2026-03-21 update power saving period to restrict weekday absence to Mon-Wed
2026-07-09 battery instead of time
2026-07-09 Add SCD sensor data and WiFi RSSI to Home Assistant integration
2026-08-08 Update sensor references from AHT to SHT4x in documentation and code
2026-08-09 Handle NaN values for temperature, humidity, CO2, and pressure in display rendering
2026-08-09 Update 3D model files for air analyzer
    [air analyzer.blend, bottom part.stl, middle part.stl]
2026-08-09 Cut radio and panel time out of the wake cycle (#2)
    * Cut radio and panel time out of the wake cycle
    Four independent power optimizations, none of which change what the device
    measures or displays.
    WiFi off before the panel refresh. All network work already finished before
    initDisplay2(), but WiFi.disconnect() ran after updateDisplay(). With
    WIFI_PS_NONE the receiver never sleeps, so the radio sat at ~70 mA through
    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
2026-08-12 Remove unused I2C device handling functions and streamline sensor initialization
    [air analyzer.blend]
2026-08-16 Enhance sensor initialization and reading logic for improved timing and reliability
    [air analyzer.blend, bottom part.stl, middle part.stl]
